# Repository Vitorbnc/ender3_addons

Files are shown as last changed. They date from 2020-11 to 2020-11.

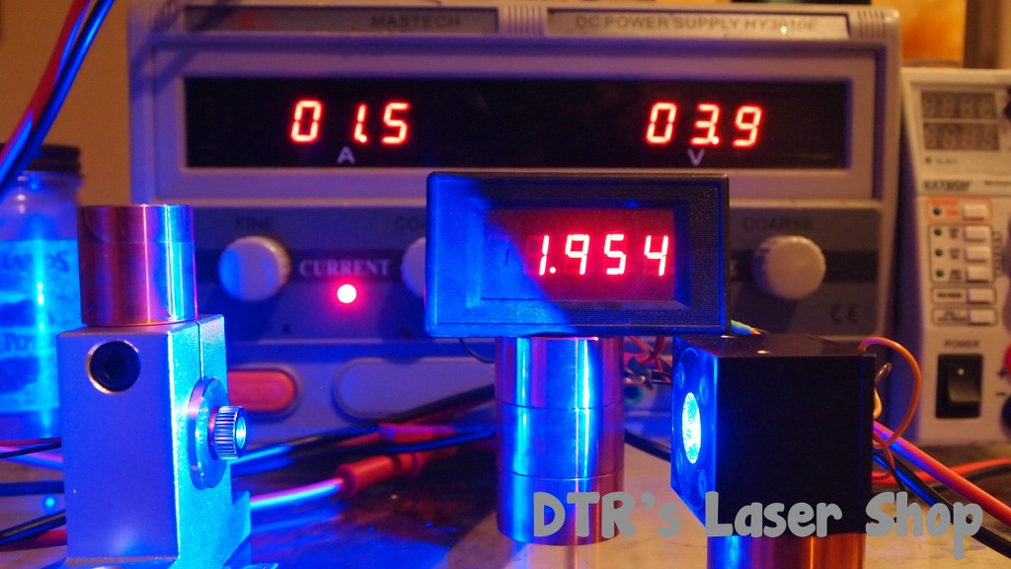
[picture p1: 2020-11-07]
Laser Engraving Module/NUBM08 Output Power x Current Test/KHAAA6.jpg

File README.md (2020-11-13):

# ender3_addons
Addons for the Creality Ender3 3D Printer, including a [laser engraver](https://github.com/Vitorbnc/ender3_addons/tree/main/Laser%20Engraving%20Module) and a [CNC mill (Fresa CNC)](https://github.com/Vitorbnc/ender3_addons/tree/main/Fresa%20CNC%20para%20Impressora%203D). The mill works very well for drilling PCBs. 

There's a [guide to building the CNC mill here](https://hackaday.io/project/174733-ender-3-pcb-drilling).

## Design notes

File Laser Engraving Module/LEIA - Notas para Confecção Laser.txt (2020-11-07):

IMPORTANTE: USE UMA FONTE MONSTRA PARA TESTAR (tipo 10A)
** Há esquemáticos nesta pasta 
** Veja a última atualização para ver a ligação mais atual

--- Geral 
0. COMPRE UM ÓCULOS DE PROTEÇÃO (OD5 OU MAIOR) - Um ótimo óculos (embora não certificado especificamente para laser) é o UVEX Ultra-Spec 2000 lente laranja (S0360)
1. Pode ser necessário retirar a lente que vem com o diodo de 9mm (NUBM08 no caso). Use uma morsa e aperte bem a saída óptica, depois retire a base com um alicate.
1. Obs.: Faça o teste com a lente original também (sem retirá-la)

--- Driver
1.Use um driver de Corrente Constante (CC). Não use fios finos ou muito longos e finos entre a saída do driver e o diodo, ou ele nunca vai receber a corrente máxima programada por causa da queda de tensão nos fios.
	Observe não só os fios mas também soldas e conectores.
2.Se os fios estão OK mas você não atingiu a corrente, teste com outra fonte.  Pode ser necessário usa uma fonte de tensão maior ou maior capacidade de corrente.
3. Não culpe o diodo prematuramente. Na maioria das vezes, estes 3 fatores (driver, fios e fonte) são os vilões.
4.Estou usando agora um driver "Old School" com LM338 @ 3.12A e fonte monstra 12V de PC
PWM topíssimo com IRF3205 em série com o negativo do diodo NUBM08, corrente estável, show de bola!

--- Da Ender 3 e similares
1. Você vai usar os fios do cooler lateral do extrusor, não é necessário retirá-lo, apenas "puxar" os fios (como um "T").
2. A Ender trabalha com 24V, use uma fonte 12V separada pro laser, até porque ele consumirá bastante.
3. Use um interruptor para ativar ou não a saída TTL do driver. Use um divisor de tensão com 12K+10K (Vth ~= 10V e Rth ~= 5k) para a saída TTL (O MOSFET funciona bem com 10V, mas se você precisar de 5V TTL, só use um resistor de 4.7K entre GND e o pino de entrada TTL do seu driver). 
	
4. Use um interruptor (para alta corrente, ele chaveará o fio negativo driver-diodo) e um resistor de 100 ohms entre seus terminais para selecionar entre o modo "full" e um modo "dim" do laser. Este último servirá para
	testes e focalizar a luz sem que você fique cego.
	Obs.: É possível usar PWM para isso, mas este método ainda se mostrou bem útil, até mesmo como medida adicional de segurança.

5. Os comandos do laser em gcode são M106 (ON) e M107 (OFF). Usei inicialmente o software LaserGRBL, mas depois mudei para o LaserWeb.
	Edite o gcode e adicione G92 X0 Y0 Z0 na primeira linha, antes de tudo, para começar a gravar da posição atual (sem fazer "homing")
6. Ativar a "Visualização de Translações" permitirá ver o desenho no programa Cura (não necessário com o LaserWeb).

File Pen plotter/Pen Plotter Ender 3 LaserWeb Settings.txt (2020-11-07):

Escolha o diâmetro da ponta com 0.3mm a menos
Coloque para iniciar a plotagem a uma altura de 14mm

GCODE START --------------------

G21         ; Set units to mm
G90         ; Absolute positioning
M107       ;Laser off 
G1 F1800
G1 Z25  ;Move head up before homing
G28 X Y  ; Home
;G1 Y190
G28 Z ;home z
G0 Z25
G0 X52 Y49 ; Pen plotter zero position
G92 X0 Y0; Set position zero for X Y

;G1 Z9 F300;Set laser height
;G0 X49 Y28  ;Laser - Move to base edge

GCODE END ------------------------

M107          ; Switch tool off 
M84 ; Disable steppers

GCODE HOMING -----------

M107 ; tool off
G1 F1800
G1 Z25 ;Move head up before homing
G28 X Y  ; Home
G28 Z
M84 ; disable motors

TOOL ON -------------
G1 F1200
G1 Z12.4
;M106

TOOL OFF ---------
G0 F1800
G1 Z13.5
;M107

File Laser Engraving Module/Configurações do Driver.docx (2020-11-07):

Laser Modes: 1.Jumper & 2Ω res.: 1A (1.14W) 2.No jumper,2Ω res. bypass:3.12A (4.55W) 3.Jumper, 2Ω res. bypass: 3.79A (5.40W) PS.: Optical power values estimated

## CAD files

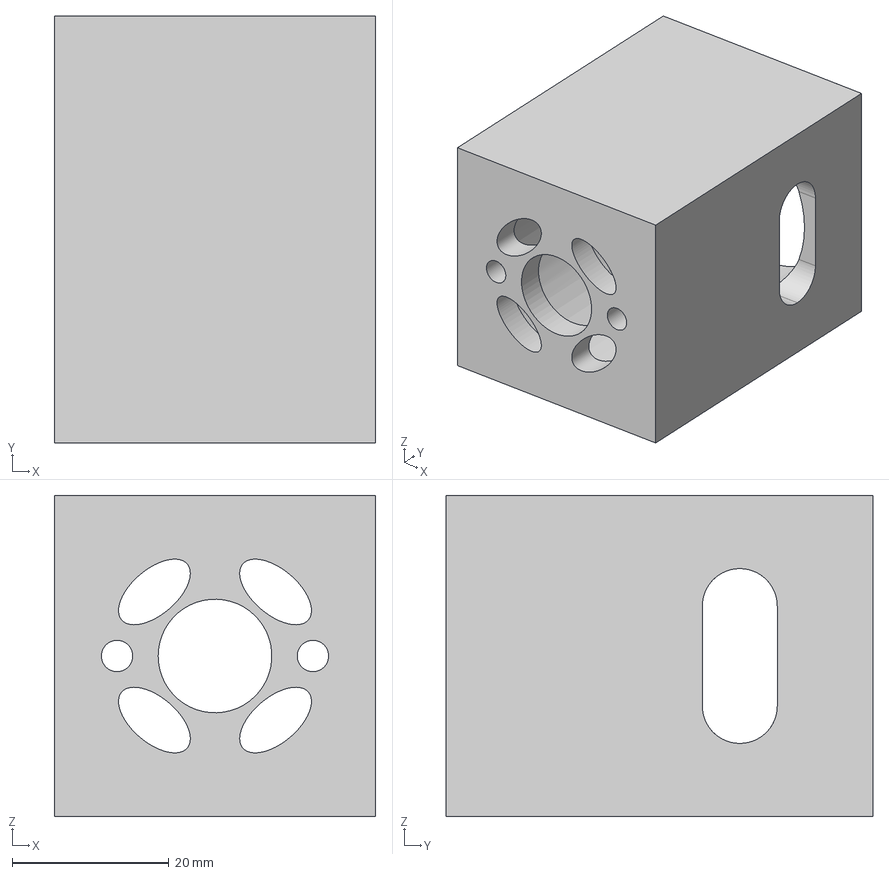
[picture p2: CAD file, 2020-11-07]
Fresa CNC para Impressora 3D/rs540 dc motor holder box v1 v1.step
41.0 x 54.5 x 41.0 mm

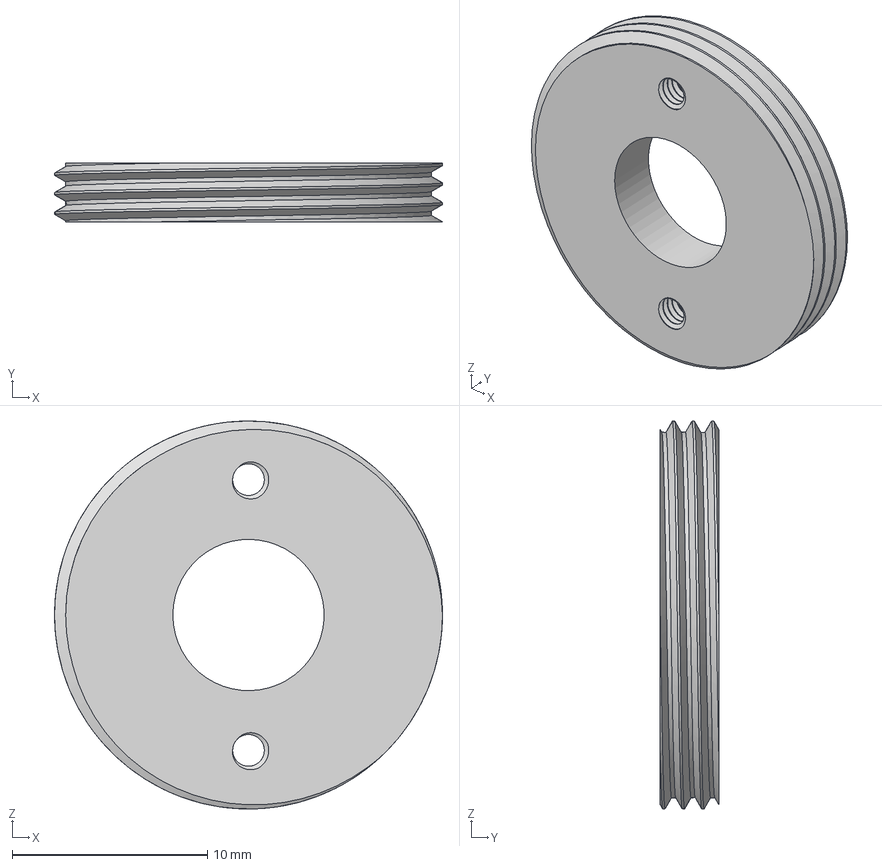
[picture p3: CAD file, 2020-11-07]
Laser Engraving Module/Filtro de Halo para o Laser/laser filter support mini v3.step
19.9 x 3.00 x 19.9 mm

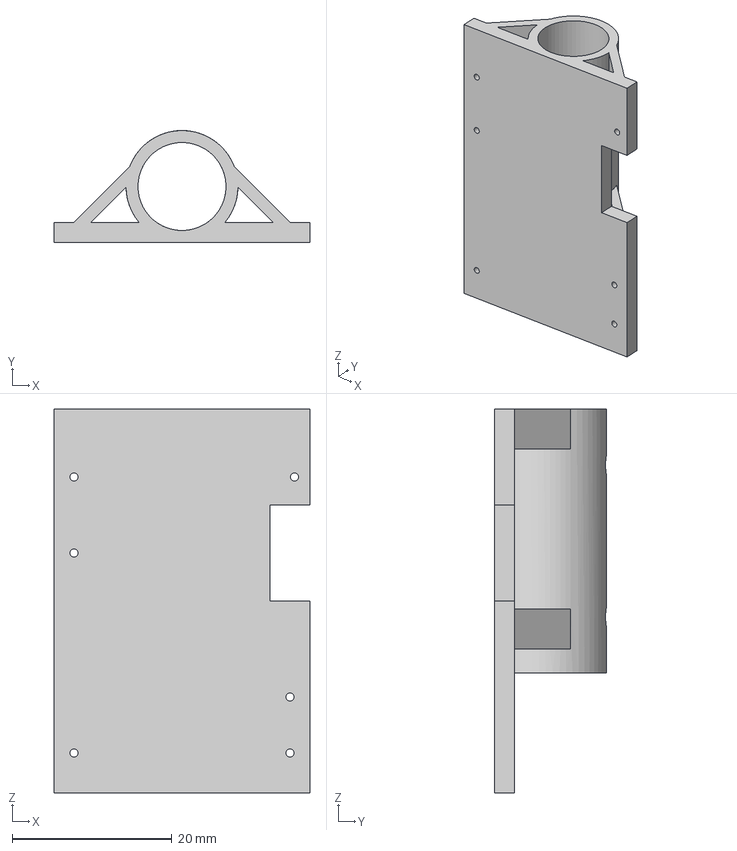
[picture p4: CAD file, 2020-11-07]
Pen plotter/Pen Holder v2.step
32.0 x 14.0 x 48.0 mm

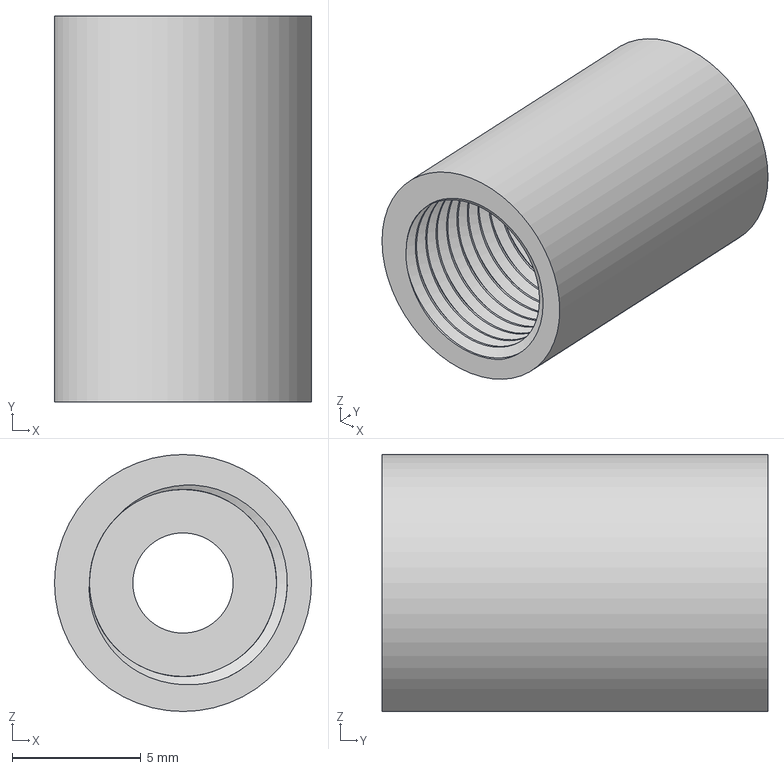
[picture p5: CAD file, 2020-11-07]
Fresa CNC para Impressora 3D/drill bit threaded holder v2.step
10.0 x 15.0 x 10.0 mm

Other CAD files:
Fresa CNC para Impressora 3D/drill bit threaded holder v2.f3d
Fresa CNC para Impressora 3D/rs540 dc motor holder box v1 v1.f3d
Laser Engraving Module/Filtro de Halo para o Laser/laser filter support mini v3.f3d
Pen plotter/Pen Holder v2.f3d

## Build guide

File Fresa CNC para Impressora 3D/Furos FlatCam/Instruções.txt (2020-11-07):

*Nota: Estas instruções foram testadas com o módulo de fresa para a ender 3 feito por mim, mas devem servir para uso geral.

Placa:
ALTERNATIVA 1:
Coloque a placa sobre um suporte de madeira sobre a mesa da impressora 3d. Use fita dupla face para grudar a placa na madeira.
Verifique se a broca e a furadeira (fresa) estão bem alinhadas, exatamente na vertical, verifique furando uma placa qualquer (já com o código)
Use broca 0.8mm
Posicione a fresa no ponto(0,0) (origem) desejado para os furos (isto é, a origem que você definiu ou definirá no KiCad), com a altura bem próxima da placa 
já fixada com fita dupla face, mas alto o suficiente pra que a fresa se desloque sem arranhar a placa.

ALTERNATIVA 2:
Coloque a placa sobre a mesa de impressão sem fita,mas com uma folha de papel cartão de 1mm por baixo e prenda os lados com grampos. O resto é igual.

1.No KiCad, crie um eixo de origem auxiliar, marcando o ponto de origem desejado no desenho da PCB.
Obs.: O eixo auxiliar pode ser qualquer coisa(vértice, via, letra,etc.), desde que seja pequena pra facilitar o alinhamento
2.Vá em Generate Drill File na seção de Plot, use o eixo auxiliar e gere um excellon
3.Abra o excellon no FlatCam
4.No FlatCam:
-Verifique se não há furos adicionais longe demais. Edite (botão direito, editar) o excellon para que os furos não sejam largos demais (deixei todos 0.8mm)
-Carregue a configuração mais nova desta pasta, certifique-se que o tamanho da ferramenta é mesmo 0.8mm
-Selecione o excellon e gere o g-code.
-Exporte o g-code para um arquivo.
5.Faça as substituições (M3->M106 e M5->M107) ou (acho melhor):
- Deixe M106 como prepend G-Code
- M107 e M84 como append G-code

6.Se você gerou g-code com preprocessor Marlin (bom para furar mais rápido), 
arraste o g-code sobre o "Marlin Excellon Fix F100.EXE" para gerar um g-code corrigido, com velocidade F100 para furos

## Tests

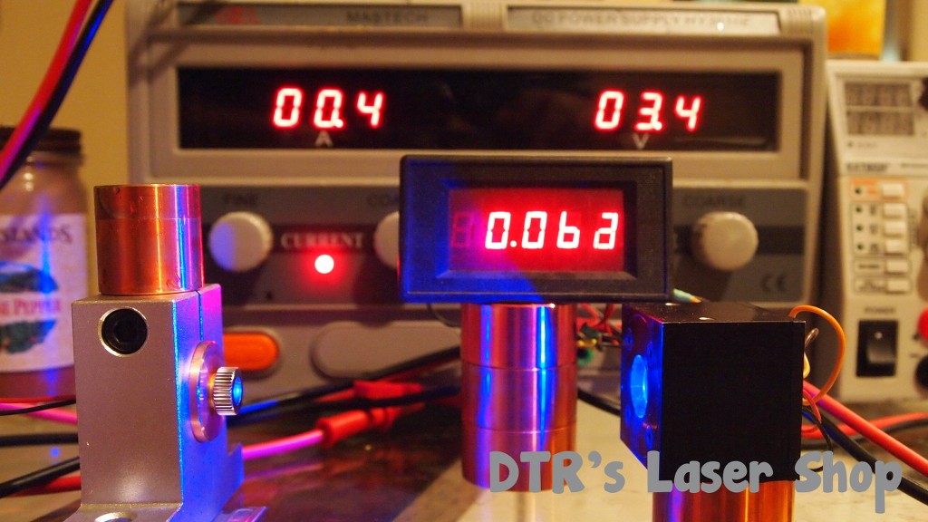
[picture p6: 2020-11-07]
Laser Engraving Module/NUBM08 Output Power x Current Test/HVaRc0.jpg

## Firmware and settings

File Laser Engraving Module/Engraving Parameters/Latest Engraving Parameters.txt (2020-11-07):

Laser Usado:
NUBM08 a 2.95A - Cerca de 4.3W estimado
Gravações feitas aproximadamente na distância focal, obtida manualmente, a olho nu, com o modo dim

------------------------------------------------------------------------------------------
Madeira:
Testado com Laser GRBL
x 52
y 30
z 14

1000mm/s

G92 X0 Y0 Z0
-------------------------------------------------------------------------------------------
PCB:
Testado com LaserWeb, G-Code v1
Z 9

1)

Tool ON:
M106
G1 F100

Tool OFF:
M107
G0 F300

Tempo Gasto:
Desenho "Shift595" - 49.7x39.3mm
Laser spot diam. 0.15mm 
1h40min 
----------------------------

2)


Tool ON:
M106
G1 F200

Tool OFF:
M107
G0 F1000

Tempo Gasto:
Desenho "Shift595" - 49.7x39.3mm
Laser spot diam. 0.15mm 
51min 

----------------------------------------------------------------------------------
Plástico/Couro:
Driver LM338 NUBM08 @3.12A - 4.55W estimado
Gravações aproximadamente na distância focal (na verdade, um pouquinho mais alto para dar suavidade, dado que o laser já está bem forte)

-Couro legítimo: cerca de 4000, invertida ou não, tudo ok

---- Couro "falso" - plástico
Desenho  "faith.svg" 
-Não invertida (queima o fundo, deixa a frente intacta)
Velocidade: 4200mm/min on e off
Tempo: 16 min
-Invertida (queima só a frente)
Velocidade: 4800
Tempo: cerca de 10min
Ficou um pouco 'fino', mas suficientemente visível



-------------------------------------------------------------------------------
Couro Legítimo
Laser NUBM08 @1A com pinhole pra filtrar o halo (tipo um filtro espacial, com a própria lente do laser)
Altura do eixo z: determinada a olho (talvez 6mm)

Velocidade: 1000mm/min ON e 2400mm/min OFF
Imagem e texto com LaserWeb

Gravação ficou ótima

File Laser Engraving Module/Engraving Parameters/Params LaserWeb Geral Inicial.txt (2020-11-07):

Configuração para o LaserWeb 4.0.996
Testada para gravar couro e plásticos.
Posicionamento manual do foco do laser
Lembre-se de desativar o "burn white" ao gerar o desenho para usar G0 (enquanto o laser está desligado) e G1 (enquanto ligado)

-Configure a área da impressora para 220x220mm

-Generator: default

-Start

G21         ; Set units to mm
G90         ; Absolute positioning
M107       ;Laser off 
G92 X0 Y0 Z0


-End

M107          ; Switch tool off 
M84 ; Disable steppers


-Homing
;homing não estabelecido


-Tool ON

G1 F4200
M106

-Tool OFF


G0 F4200
M107


-Laser Intensity

S

-Tool test duration: 0
